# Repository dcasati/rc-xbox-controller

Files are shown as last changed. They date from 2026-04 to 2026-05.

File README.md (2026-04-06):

# RC Xbox Controller

Control your RC car using an Xbox Controller over Bluetooth Low Energy (BLE) with an ESP32-WROOM microcontroller.

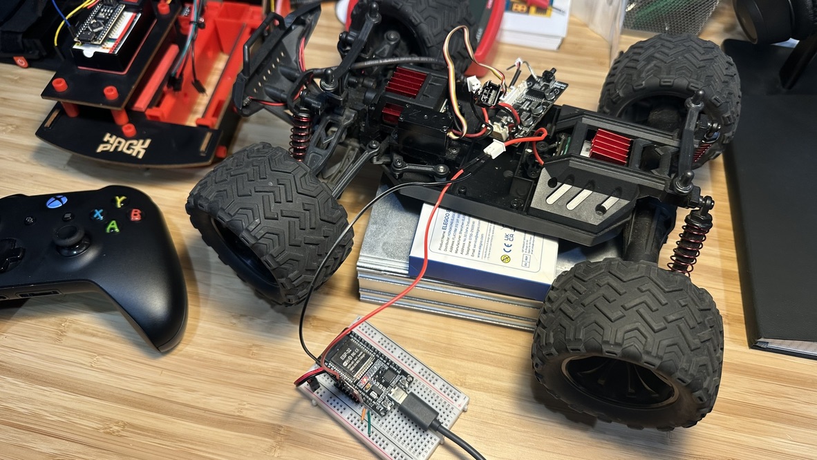
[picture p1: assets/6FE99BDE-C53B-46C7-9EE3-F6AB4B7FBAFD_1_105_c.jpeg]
RC Car


## Overview

This project replaces the standard RC car controller with an ESP32-WROOM that receives input from an Xbox Controller via BLE using [Bluepad32](https://github.com/ricardoquesada/bluepad32). The system controls:

- **Drive Motor**: Forward/backward movement using Xbox triggers (LT/RT)
- **Steering**: Left/right direction using left thumbstick X-axis
- **Headlights**: LED control toggled with the Y button

## Hardware

### Components
- **ESP32-WROOM** (4MB flash)
- **TB6612FNG H-Bridge** motor driver
- **DC Drive Motor** (rear wheels)
- **Stepper Motor** (front wheel steering)
- **LED** (headlights)
- **Xbox Controller** (Bluetooth)

### Wiring

| Component | GPIO | Function |
|---|---|---|
| Drive Motor PWM | 27 | PWMA |
| Drive Motor Direction | 25, 26 | AIN1, AIN2 |
| Steering PWM | 14 | PWMB |
| Steering Direction | 32, 33 | BIN1, BIN2 |
| Standby | 12 | STBY (HIGH) |
| Headlight LED | 4 | Output |

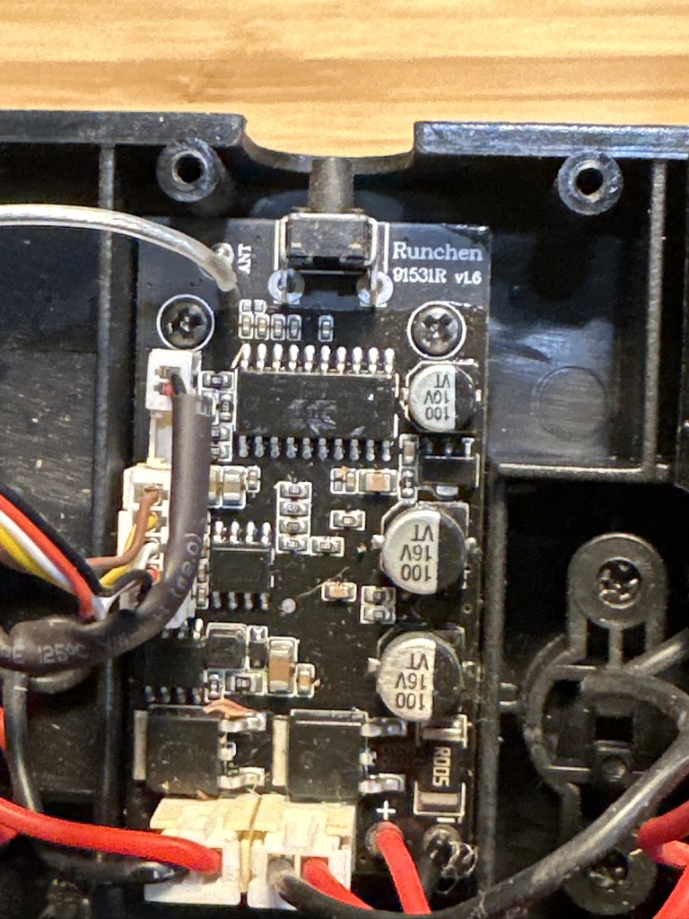
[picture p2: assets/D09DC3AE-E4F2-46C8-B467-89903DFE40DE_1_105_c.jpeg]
Hardware Setup


## Software Architecture

### Project Structure
```
rc-xbox-controller/
├── CMakeLists.txt          # ESP-IDF project config
├── sdkconfig.defaults      # Default build configuration
├── main/
│   ├── main.c              # Application entry point
│   ├── led.c/.h            # Headlight control
│   ├── motor_control.c/.h  # Drive motor (TB6612FNG Channel A)
│   ├── steering.c/.h       # Steering motor (TB6612FNG Channel B)
│   └── my_platform.c/.h    # Bluepad32 platform integration
├── hardware/               # KiCad PCB design files
├── Documents/              # Project documentation
└── assets/                 # Project images
```

### Control Mapping

| Xbox Input | Function | Range |
|---|---|---|
| Left Trigger (LT) | Forward speed | 0-1023 → PWM |
| Right Trigger (RT) | Reverse speed | 0-1023 → PWM |
| Left Stick X-axis | Steering | -512 to +511 |
| Y Button | Toggle headlights | On/Off |

## Build & Flash

### Prerequisites

1. **ESP-IDF v5.4.1** or later
   ```bash
   # Follow ESP-IDF installation guide
   # https://docs.espressif.com/projects/esp-idf/en/latest/esp32/get-started/
   ```

2. **Bluepad32** component
   ```bash
   # Clone Bluepad32 to your ESP components directory
   cd ~/esp
   git clone --recursive https://github.com/ricardoquesada/bluepad32.git
   ```

3. **BTstack** integration
   ```bash
   cd ~/esp/bluepad32/external/btstack
   python integrate_btstack.py
   ```

### Build

```bash
# Set up ESP-IDF environment
get_idf

# Navigate to project directory
cd /path/to/rc-xbox-controller

# Set target (first time only)
idf.py set-target esp32

# Build project
idf.py build

# Flash to ESP32
idf.py -p /dev/ttyUSB0 flash monitor
```

### Wi-Fi Configuration

Wi-Fi credentials are needed for OTA firmware updates. Since `sdkconfig` is gitignored, each developer must configure credentials locally.

**Option 1 — Interactive menu (recommended):**

```bash
get_idf
idf.py menuconfig
```

Navigate to **RC Xbox Controller Config** and set:
- **Wi-Fi SSID** — your network name
- **Wi-Fi Password** — your network password

Save and exit. Then rebuild with `idf.py build`.

**Option 2 — Command line (no menu):**

```bash
idf.py menuconfig --set "CONFIG_RC_WIFI_SSID=YourNetworkName" --set "CONFIG_RC_WIFI_PASSWORD=YourPassword"
idf.py build
```

**Option 3 — Edit `sdkconfig.defaults` (shared defaults):**

Add your credentials to `sdkconfig.defaults` if you want them as the default for new builds:

```
CONFIG_RC_WIFI_SSID="YourNetworkName"
CONFIG_RC_WIFI_PASSWORD="YourPassword"
```

Then do a clean build: `idf.py fullclean && idf.py build`

> **Note:** Do not commit real credentials. The defaults in `Kconfig.projbuild` are placeholder values (`myssid` / `mypassword`).

### OTA Firmware Update

Once connected to Wi-Fi, the ESP32 starts an HTTP server on port 80. To update firmware over-the-air:

1. Build the project: `idf.py build`
2. Find the ESP32's IP address in the serial monitor output (logged on boot)
3. Open `http://<ESP32_IP>/` in a browser
4. Select the `.bin` file from `build/rc_xbox_controller.bin`
5. Click **Upload & Flash** — the device reboots automatically

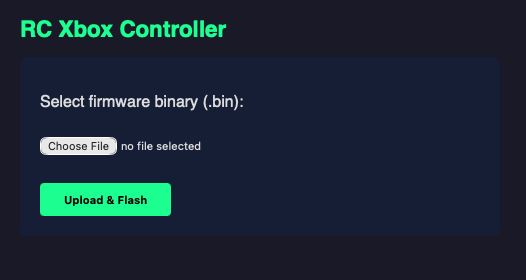
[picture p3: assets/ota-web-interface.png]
OTA Web Interface


## Usage

1. **Power on** the ESP32 and the RC car
2. **Pair** your Xbox Controller with the ESP32 (automatic BLE discovery)
3. **Drive**:
   - Press **LT** to move forward
   - Press **RT** to move backward
   - Move **left stick** left/right to steer
   - Press **Y** to toggle headlights
4. **Safety**: Motors automatically stop when the controller disconnects

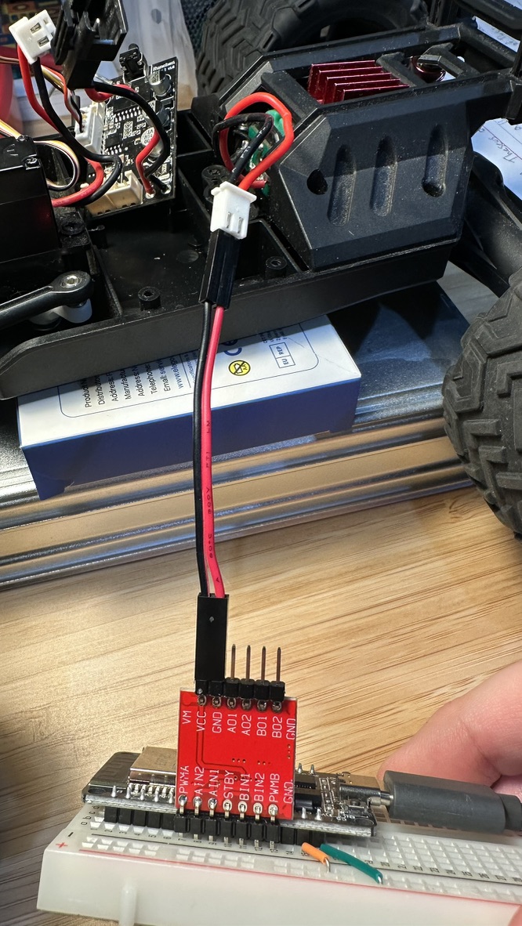
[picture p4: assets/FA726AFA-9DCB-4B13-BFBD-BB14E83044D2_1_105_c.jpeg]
Working Project


## Implementation Status

### ✅ Phase 1 — Complete
- [x] BLE Xbox Controller integration (Bluepad32)
- [x] Drive motor control (forward/backward via triggers)
- [x] Steering control (via thumbstick)
- [x] LED headlight toggle (Y button)
- [x] Disconnect safety (motors stop on BLE disconnect)

### ✅ Phase 2 — Complete
- [x] Wi-Fi station connectivity
- [x] OTA firmware updates via web interface
- [x] Structured logging with ESP_LOG per-module tags
- [ ] Tuning & polish (Task 2.5)

## Development Notes

- **Dead-zone threshold**: 5% trigger range prevents motor hum at rest
- **Stepper limits**: Max step count configured to prevent mechanical over-travel
- **PWM frequency**: Default LEDC configuration for smooth motor control
- **BLE callbacks**: High-priority FreeRTOS task processes Bluepad32 events

## References

- [ESP-IDF Documentation](https://docs.espressif.com/projects/esp-idf/en/latest/esp32/)
- [Bluepad32 GitHub](https://github.com/ricardoquesada/bluepad32)
- [TB6612FNG Datasheet](https://www.sparkfun.com/datasheets/Robotics/TB6612FNG.pdf)
- [Project Documentation](Documents/)

## Gallery

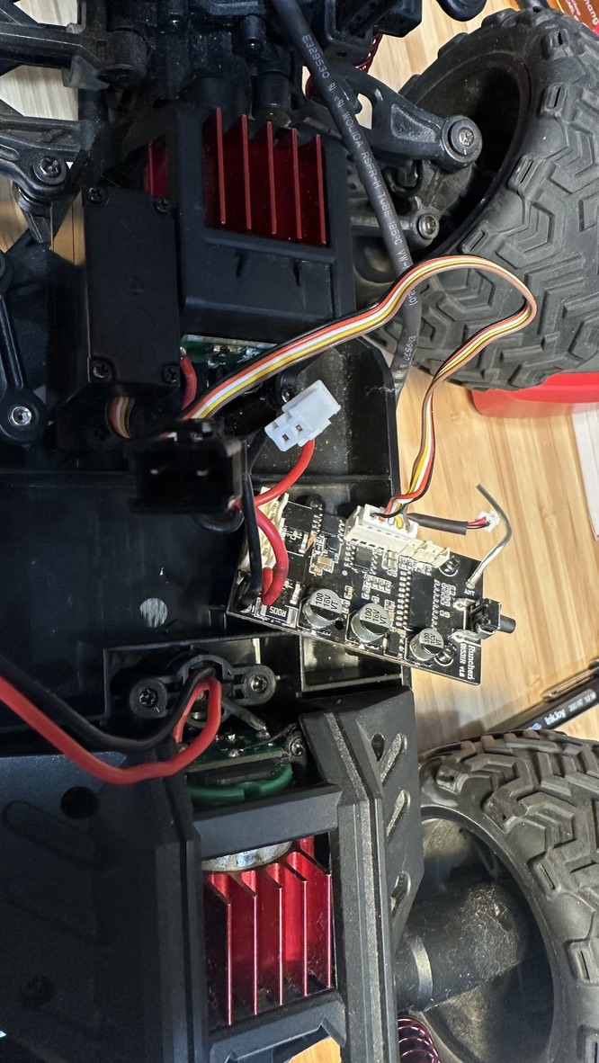
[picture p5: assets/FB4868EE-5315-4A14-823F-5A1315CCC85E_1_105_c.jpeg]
Car Interior


## License

MIT License - See LICENSE file for details

## Contributing

Pull requests welcome! Please follow ESP-IDF coding standards and test thoroughly before submitting.

## Author

Built with ESP-IDF, Bluepad32, and ❤️ for RC cars

---

**Repository**: https://github.com/dcasati/rc-xbox-controller

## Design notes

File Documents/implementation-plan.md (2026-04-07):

# Implementation Plan
## RC Xbox Controller — ESP32-WROOM

Based on [FSD.md](FSD.md) v1.0

---

## Project Structure

```
rc-xbox-controller/
├── CMakeLists.txt
├── sdkconfig.defaults
├── partitions.csv                  # OTA partition table
├── main/
│   ├── CMakeLists.txt
│   ├── main.c                      # App entry, task init
│   ├── Kconfig.projbuild           # Wi-Fi SSID/password menu
│   ├── ble_controller.c/.h         # Bluepad32 BLE host
│   ├── motor_control.c/.h          # TB6612FNG Channel A (drive)
│   ├── steering.c/.h               # TB6612FNG Channel B (stepper)
│   ├── led.c/.h                    # Headlight GPIO
│   ├── ota.c/.h                    # OTA update handler
│   ├── wifi.c/.h                   # Wi-Fi STA connection
│   └── webserver.c/.h              # HTTP server for OTA upload
├── components/
│   └── bluepad32/                  # Bluepad32 (git submodule)
└── Documents/
    ├── FSD.md
    └── rc-xbox-controller-project-idea.md
```

---

## Phase 1 — Motor Control & BLE Driving

### Task 1.1: Project Scaffolding
- [x] Create ESP-IDF project structure (`CMakeLists.txt`, `main/`)
- [x] Add Bluepad32 as a component (git submodule under `components/`)
- [x] Configure `sdkconfig.defaults` for ESP32-WROOM (BLE enabled, flash 4MB)
- [x] Set target to `esp32`, verify blank project builds
- **Depends on:** nothing

### Task 1.2: BLE Controller Integration
- [x] Implement `ble_controller.c/.h` — init Bluepad32, register callbacks
- [x] Handle `onConnectedGamepad` / `onDisconnectedGamepad` events
- [x] Parse Xbox Controller inputs: LT, RT, left thumbstick X-axis, Y button
- [x] Log raw input values over serial for validation
- **Depends on:** 1.1
- **Validates:** BLE-01, BLE-02, BLE-03

### Task 1.3: Drive Motor Control (TB6612FNG Channel A)
- [x] Implement `motor_control.c/.h`
- [x] Configure LEDC PWM on GPIO 27 (PWMA), GPIOs 25/26 (AIN1/AIN2)
- [x] Configure GPIO 12 (STBY) — pull HIGH on init
- [x] `motor_set_speed(int16_t speed)` — positive = forward, negative = reverse, 0 = brake
- [x] Map LT (0–1023) → forward PWM, RT (0–1023) → reverse PWM
- [x] Add dead-zone threshold (~5% of trigger range) to avoid motor hum at rest
- **Depends on:** 1.1
- **Validates:** MOT-01 through MOT-05

### Task 1.4: Steering Control (TB6612FNG Channel B)
- [x] Implement `steering.c/.h`
- [x] Configure LEDC PWM on GPIO 14 (PWMB), GPIOs 32/33 (BIN1/BIN2)
- [x] `steering_set_position(int16_t x_axis)` — map thumbstick X to stepper direction/speed
- [x] Add configurable max step count constant to prevent mechanical over-travel
- [x] Center position (thumbstick = 0) → stop stepper
- **Depends on:** 1.1
- **Validates:** STR-01 through STR-05

### Task 1.5: End-to-End Integration
- [x] Wire BLE callbacks → motor + steering functions in `main.c`
- [x] Create `ble_task` (FreeRTOS, priority high) — poll Bluepad32
- [x] Create `motor_task` (FreeRTOS, priority high) — consume input queue, apply PWM
- [x] Add BLE disconnect safety: stop motors + stepper on disconnect
- [x] Flash to ESP32, test with Xbox Controller + motors on bench
- **Depends on:** 1.2, 1.3, 1.4
- **Validates:** BLE-04, full Phase 1

### Phase 1 Milestone
> Xbox Controller connected over BLE drives front+rear DC motors via triggers and steers via thumbstick. Disconnect stops all outputs.

---

## Phase 2 — Headlights & Enhancements

### Task 2.1: Headlight LED Control
- [x] Implement `led.c/.h`
- [x] Configure GPIO 13 as output
- [x] `led_toggle()`, `led_set(bool on)`, `led_off()`
- [x] Wire Y button press (with debounce) → `led_toggle()`
- [x] Call `led_off()` on BLE disconnect
- **Depends on:** Phase 1
- **Validates:** LED-01, LED-02, LED-03

### Task 2.2: Wi-Fi Station Connection
- [x] Implement `wifi.c/.h`
- [x] Add `Kconfig.projbuild` for SSID/password configuration
- [x] Connect to Wi-Fi on boot using ESP-IDF `esp_wifi` API
- [x] Log IP address on successful connection
- **Depends on:** Phase 1
- **Validates:** OTA-03

### Task 2.3: OTA Web Interface
- [x] Implement `webserver.c/.h` — start `httpd_server` on port 80
- [x] Serve HTML upload form at `GET /`
- [x] Handle firmware binary upload at `POST /ota`
- [x] Implement `ota.c/.h` — write to OTA partition, validate, reboot
- [x] Create OTA partition table (`partitions.csv`: factory + ota_0 + ota_1)
- **Depends on:** 2.2
- **Validates:** OTA-01, OTA-02

### Task 2.4: Logging
- [x] Implement structured serial logging for all subsystems
- [x] Log: BLE state, trigger values, PWM duty, thumbstick X, LED state
- [x] Use ESP-IDF `ESP_LOG` macros with per-module tags
- **Depends on:** Phase 1
- **Validates:** OTA-04, OTA-05

### Task 2.5: Tuning & Polish
- [ ] Tune dead-zone for trigger center (~5%) and thumbstick center (~10%)
- [ ] Tune max steering angle / step count
- [ ] Verify latency < 50 ms (BLE input → motor output)
- [ ] Stress test: 1+ hour continuous operation
- **Depends on:** 2.1, 2.3, 2.4
- **Validates:** NFR-01, NFR-02, NFR-03

### Phase 2 Milestone
> Full system operational: BLE driving, headlights, Wi-Fi OTA, serial logging. Ready for in-car testing.

---

## GPIO Summary

| GPIO | Function | Direction |
|---|---|---|
| 4 | Front LED | Output |
| 12 | PWMB (steering PWM) | PWM Output |
| 14 | BIN2 (steer dir B) | Output |
| 25 | AIN1 (drive dir A) | Output |
| 26 | TB6612FNG STBY | Output |
| 27 | BIN1 (steer dir A) | Output |
| 32 | PWMA (drive PWM) | PWM Output |
| 33 | AIN2 (drive dir B) | Output |

---

## Dependencies

| Dependency | Version | Source |
|---|---|---|
| ESP-IDF | v5.4.1 | `~/esp/esp-idf` (installed) |
| [Bluepad32](https://github.com/ricardoquesada/bluepad32) | latest | `components/bluepad32` (git submodule) |

---

## Build & Flash

```bash
get_idf                              # activate ESP-IDF environment
cd /Volumes/Extreme\ SSD/src/rc-xbox-controller
idf.py set-target esp32
idf.py build
idf.py -p /dev/cu.usbserial-* flash monitor
```

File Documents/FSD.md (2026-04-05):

# Functional Specification Document
## RC Xbox Controller — ESP32-WROOM

**Version:** 1.0  
**Date:** April 4, 2026  
**Repository:** https://github.com/dcasati/rc-xbox-controller

---

## 1. Overview

This project replaces the standard RC car controller with an Xbox Controller connected over BLE to an ESP32-WROOM. The ESP32 acts as the BLE host (via [Bluepad32](https://github.com/ricardoquesada/bluepad32)), interprets controller inputs, and drives the car's motors and headlights through a TB6612FNG H-Bridge motor driver.

---

## 2. System Architecture

```
[Xbox Controller]
      |
      | BLE (Bluepad32)
      |
[ESP32-WROOM]
      |
      |--- UART/USB -------> Serial Logging
      |--- Wi-Fi ----------> OTA Web Interface
      |
[TB6612FNG H-Bridge] (VM = 5V)
      |
      |--- Channel A (PWM/DIR) ---> Front + Rear DC Motors (propulsion, wired in parallel)
      |
      |--- Channel B (PWM/DIR) ---> Steering Motor (DC + potentiometer feedback)
      |
      |--- GPIO -------> Front LED (headlights)
```

---

## 3. Hardware Components

| Component | Description |
|---|---|
| ESP32-WROOM | Main microcontroller; BLE host, motor control |
| Xbox Controller | User input device; connects over BLE |
| TB6612FNG H-Bridge | Dual-channel motor driver; VM = 5V |
| Front DC Motor | Propulsion — forward / backward (wired in parallel with rear) |
| Rear DC Motor | Propulsion — forward / backward (wired in parallel with front) |
| Front Steering Servo | Steering — DC motor + potentiometer feedback, driven via TB6612FNG Channel B |
| Front LED | Headlights — on / off |
| USB Cable | Power + serial logging |

---

## 4. Functional Requirements

### 4.1 BLE & Controller Connectivity

| ID | Requirement |
|---|---|
| BLE-01 | The ESP32 shall initialize as a BLE host using the [Bluepad32](https://github.com/ricardoquesada/bluepad32) library. |
| BLE-02 | The ESP32 shall accept a pairing request from an Xbox Controller. |
| BLE-03 | The system shall reconnect automatically to the last paired controller on power-up. |
| BLE-04 | Controller disconnection shall immediately stop all motor outputs and turn off headlights. |

### 4.2 Propulsion (Front + Rear DC Motors)

The front and rear DC motors are wired in parallel on TB6612FNG Channel A. They always run at the same speed and direction. Motor supply voltage is 5V.

| ID | Requirement |
|---|---|
| MOT-01 | The left trigger (LT) shall control forward drive speed; the right trigger (RT) shall control reverse drive speed. |
| MOT-02 | Pressing LT shall drive the motors in the forward direction. |
| MOT-03 | Pressing RT shall drive the motors in reverse. |
| MOT-04 | Motor speed shall be proportional to trigger deflection (0–100% PWM). |
| MOT-05 | Releasing both triggers shall brake the motors (STBY or coast configurable). |

### 4.3 Steering (Front Servo)

| ID | Requirement |
|---|---|
| STR-01 | The left thumbstick X-axis shall control the front steering servo. |
| STR-02 | Deflecting left shall move the servo to the left steering position. |
| STR-03 | Deflecting right shall move the servo to the right steering position. |
| STR-04 | Returning the thumbstick to center shall return the servo to the center position. |
| STR-05 | Servo pulse range (1.0–2.0ms at 50Hz) shall be configurable to prevent mechanical over-travel. |

### 4.4 Headlights (Front LED)

| ID | Requirement |
|---|---|
| LED-01 | Pressing the **Y button** on the Xbox Controller shall toggle the front LED on and off. |
| LED-02 | The LED state shall persist across steering and speed changes. |
| LED-03 | On BLE disconnect, the LED shall turn off. |

### 4.5 OTA & Logging

| ID | Requirement |
|---|---|
| OTA-01 | The firmware shall support OTA updates over Wi-Fi using the ESP-IDF OTA partition scheme. |
| OTA-02 | A basic web interface (HTTP server on the ESP32) shall allow the user to upload a new firmware binary. |
| OTA-03 | The ESP32 shall connect to a configured Wi-Fi network on boot (SSID/password stored in NVS or sdkconfig). |
| OTA-04 | Serial logging shall be available over USB at 115200 baud. |
| OTA-05 | Log output shall include BLE connection state, controller input values, motor PWM duty cycles, and LED state. |

---

## 5. Xbox Controller Button Mapping

| Xbox Input | Function |
|---|---|
| Left Trigger (LT) | Drive forward (proportional) |
| Right Trigger (RT) | Drive backward (proportional) |
| Left Thumbstick X+ | Steer right |
| Left Thumbstick X− | Steer left |
| Y Button | Toggle headlights |

> Additional mappings (e.g., bumpers for turbo, Menu for OTA trigger) to be defined in Phase 2.

---

## 6. Pin Mapping (Verified)

| Signal | ESP32 Pin | ESP32-WROOM-32 Module Pin | TB6612FNG Pin | Function |
|---|---|---|---|---|
| AIN1 | GPIO 25 | IO25 (pin 10) | pin 14 | Drive motors direction A |
| AIN2 | GPIO 33 | IO33 (pin 9) | pin 15 | Drive motors direction B |
| PWMA | GPIO 32 | IO32 (pin 8) | pin 16 | Drive motors PWM |
| STBY | GPIO 26 | IO26 (pin 11) | — | H-Bridge standby (HIGH = enabled) |
| BIN1 | GPIO 27 | IO27 (pin 12) | pin 12 | Steering motor direction A |
| BIN2 | GPIO 14 | IO14 (pin 13) | pin 11 | Steering motor direction B |
| PWMB | GPIO 12 | IO12 (pin 14) | pin 10 | Steering motor PWM |
| POT | GPIO 34 | IO34 (pin 6) | — | Steering potentiometer wiper (ADC input) |
| LED | GPIO 13 | IO13 (pin 16) | — | Front LED headlight |
| VDD | 3.3V | VDD (pin 2) | VCC (pin 2) | Logic power |
| GND | GND | GND (pin 1) | GND (pins 3,8,9) | Common ground |
| VM | — | — | VM (pin 1) | Motor power: 5V (regulated from battery) |

### TB6612FNG Motor Outputs

| TB6612FNG Pin | Connected to | Notes |
|---|---|---|
| AO1 (pin 4) | Drive motor wire 1 | Front + rear DC motors wired in parallel |
| AO2 (pin 5) | Drive motor wire 2 | Swap AO1/AO2 if direction is reversed |
| BO1 (pin 7) | Steering servo RED wire | Motor + |
| BO2 (pin 6) | Steering servo BLACK wire | Motor − |

### 5-Wire Steering Servo

| Wire Color | Connect to | Function |
|---|---|---|
| Red | TB6612FNG BO1 (pin 7) | Motor + |
| Black | TB6612FNG BO2 (pin 6) | Motor − |
| White | ESP32 3.3V | Potentiometer VCC |
| Yellow | ESP32 GPIO 34 | Potentiometer wiper (ADC) |
| Brown | ESP32 GND | Potentiometer GND |

### Additional Components

| Component | Connection | Notes |
|---|---|---|
| 100nF ceramic cap | GPIO 34 ↔ GND | Required: filters motor EMI on ADC |
| 220Ω resistor | GPIO 13 → LED → GND | Current limiting for headlight LED |
| 7.4V Li-ion battery | VM + GND on TB6612FNG | 2S 18650, 1500mAh (regulated to 5V for VM) |

---

## 7. Software Architecture

### 7.1 Firmware Components

| Component | Responsibility |
|---|---|
| `main.c` | App entry point; task initialization |
| `ble_controller.c/.h` | Bluepad32 integration; BLE event handling |
| `motor_control.c/.h` | TB6612FNG PWM/direction control for both motors |
| `steering.c/.h` | DC motor + potentiometer closed-loop position control |
| `led.c/.h` | Headlight GPIO control |
| `ota.c/.h` | OTA update handler |
| `wifi.c/.h` | Wi-Fi station connection |
| `webserver.c/.h` | HTTP server for OTA upload page |

### 7.2 FreeRTOS Tasks

| Task | Priority | Description |
|---|---|---|
| `ble_task` | High | Polls Bluepad2 for controller events |
| `motor_task` | High | Applies PWM updates from BLE input queue |
| `ota_task` | Low | HTTP server for OTA firmware upload |
| `log_task` | Low | Periodic status logging over UART |

### 7.3 Framework & Libraries

| Tool / Library | Purpose |
|---|---|
| ESP-IDF v5.4.x | Base SDK, FreeRTOS, Wi-Fi, OTA, BLE |
| [Bluepad32](https://github.com/ricardoquesada/bluepad32) | Xbox Controller BLE host library |
| ESP32-Workbench | Flashing, testing, serial monitoring |

---

## 8. Implementation Phases

### Phase 1 — Motor Control & BLE Driving
- [ ] Initialize Bluepad2 and pair with Xbox Controller
- [ ] Implement rear DC motor forward/backward via TB6612FNG
- [ ] Implement front stepper motor left/right steering
- [ ] Map thumbstick axes to motor PWM
- [ ] Validate over BLE end-to-end

### Phase 2 — Headlights & Enhancements
- [ ] Implement LED toggle on Y button press
- [ ] Add BLE disconnect safety stop
- [ ] Add OTA update support
- [ ] Serial logging for all subsystems
- [ ] Tuning: dead-zone on thumbstick center, max steering angle

---

## 9. Non-Functional Requirements

| ID | Requirement |
|---|---|
| NFR-01 | BLE input-to-motor latency shall be < 50 ms. |
| NFR-02 | Firmware shall fit within 2 MB flash (single OTA partition scheme). |
| NFR-03 | System shall be stable for continuous operation > 1 hour without reboot. |
| NFR-04 | All source code shall be hosted at https://github.com/dcasati/rc-xbox-controller. |

---

## 10. Resolved Questions

| # | Question | Answer |
|---|---|---|
| 1 | Is the front motor a true stepper (step/dir) or a DC motor used for steering? | It is a servo. Direct PWM from ESP32 GPIO (no H-Bridge needed). Two DC motors (front + rear) for propulsion. |
| 2 | What is the supply voltage for the motors? | Measured 4.6–5V (within TB6612FNG range). |
| 3 | Should OTA be triggered automatically or via a dedicated button press? | Basic web interface served by the ESP32 over Wi-Fi. |
| 4 | Is Wi-Fi available in the RC car environment? | Yes. Wi-Fi OTA will be used. |

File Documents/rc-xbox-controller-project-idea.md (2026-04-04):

# rc xbox controller project

The rc xbox controller a solution consisting of an ESP32 wroom that replaces the standard controller from a RC car. The XBOX Controller communicates with the ESP32 over BLE using [Bluepad32](https://github.com/ricardoquesada/bluepad32). Together allow for someone to operate the car using a XBOX controller.

## Main Function

I want to use an XBOX Controller to control my RC car over BLE on ESP32-WROOM.

The ESP32 should control the car two motors. There is a step motor that controls the left and right direction of the front wheels. There is another motor on the back that controls the speed of the RC car. There is also a LED in front of the car that functions as headlights.

To control the motors, we will use a TB6612FNG H-Bridge 

Because we use a USB for the project, the ESP32 should use OTA flashing and logging. 

## Implementation Phases

1. Implement all of the basic ESP32 functions, including driving forward, backward and turning left and right using the xbox controller over BLE.
2. Implement a function that allows for the LEDs to be turned on and off using the xbox controller over BLE.

## Tools

Use ESP-IDF and Apple native tools for the project.
Use the ESP32-workbench (https://github.com/SensorsIot/Universal-ESP32-Workbench) with its skills for flashing, testing.

Create a new GitHub Repository on https://github.com/dcasati/rc-xbox-controller

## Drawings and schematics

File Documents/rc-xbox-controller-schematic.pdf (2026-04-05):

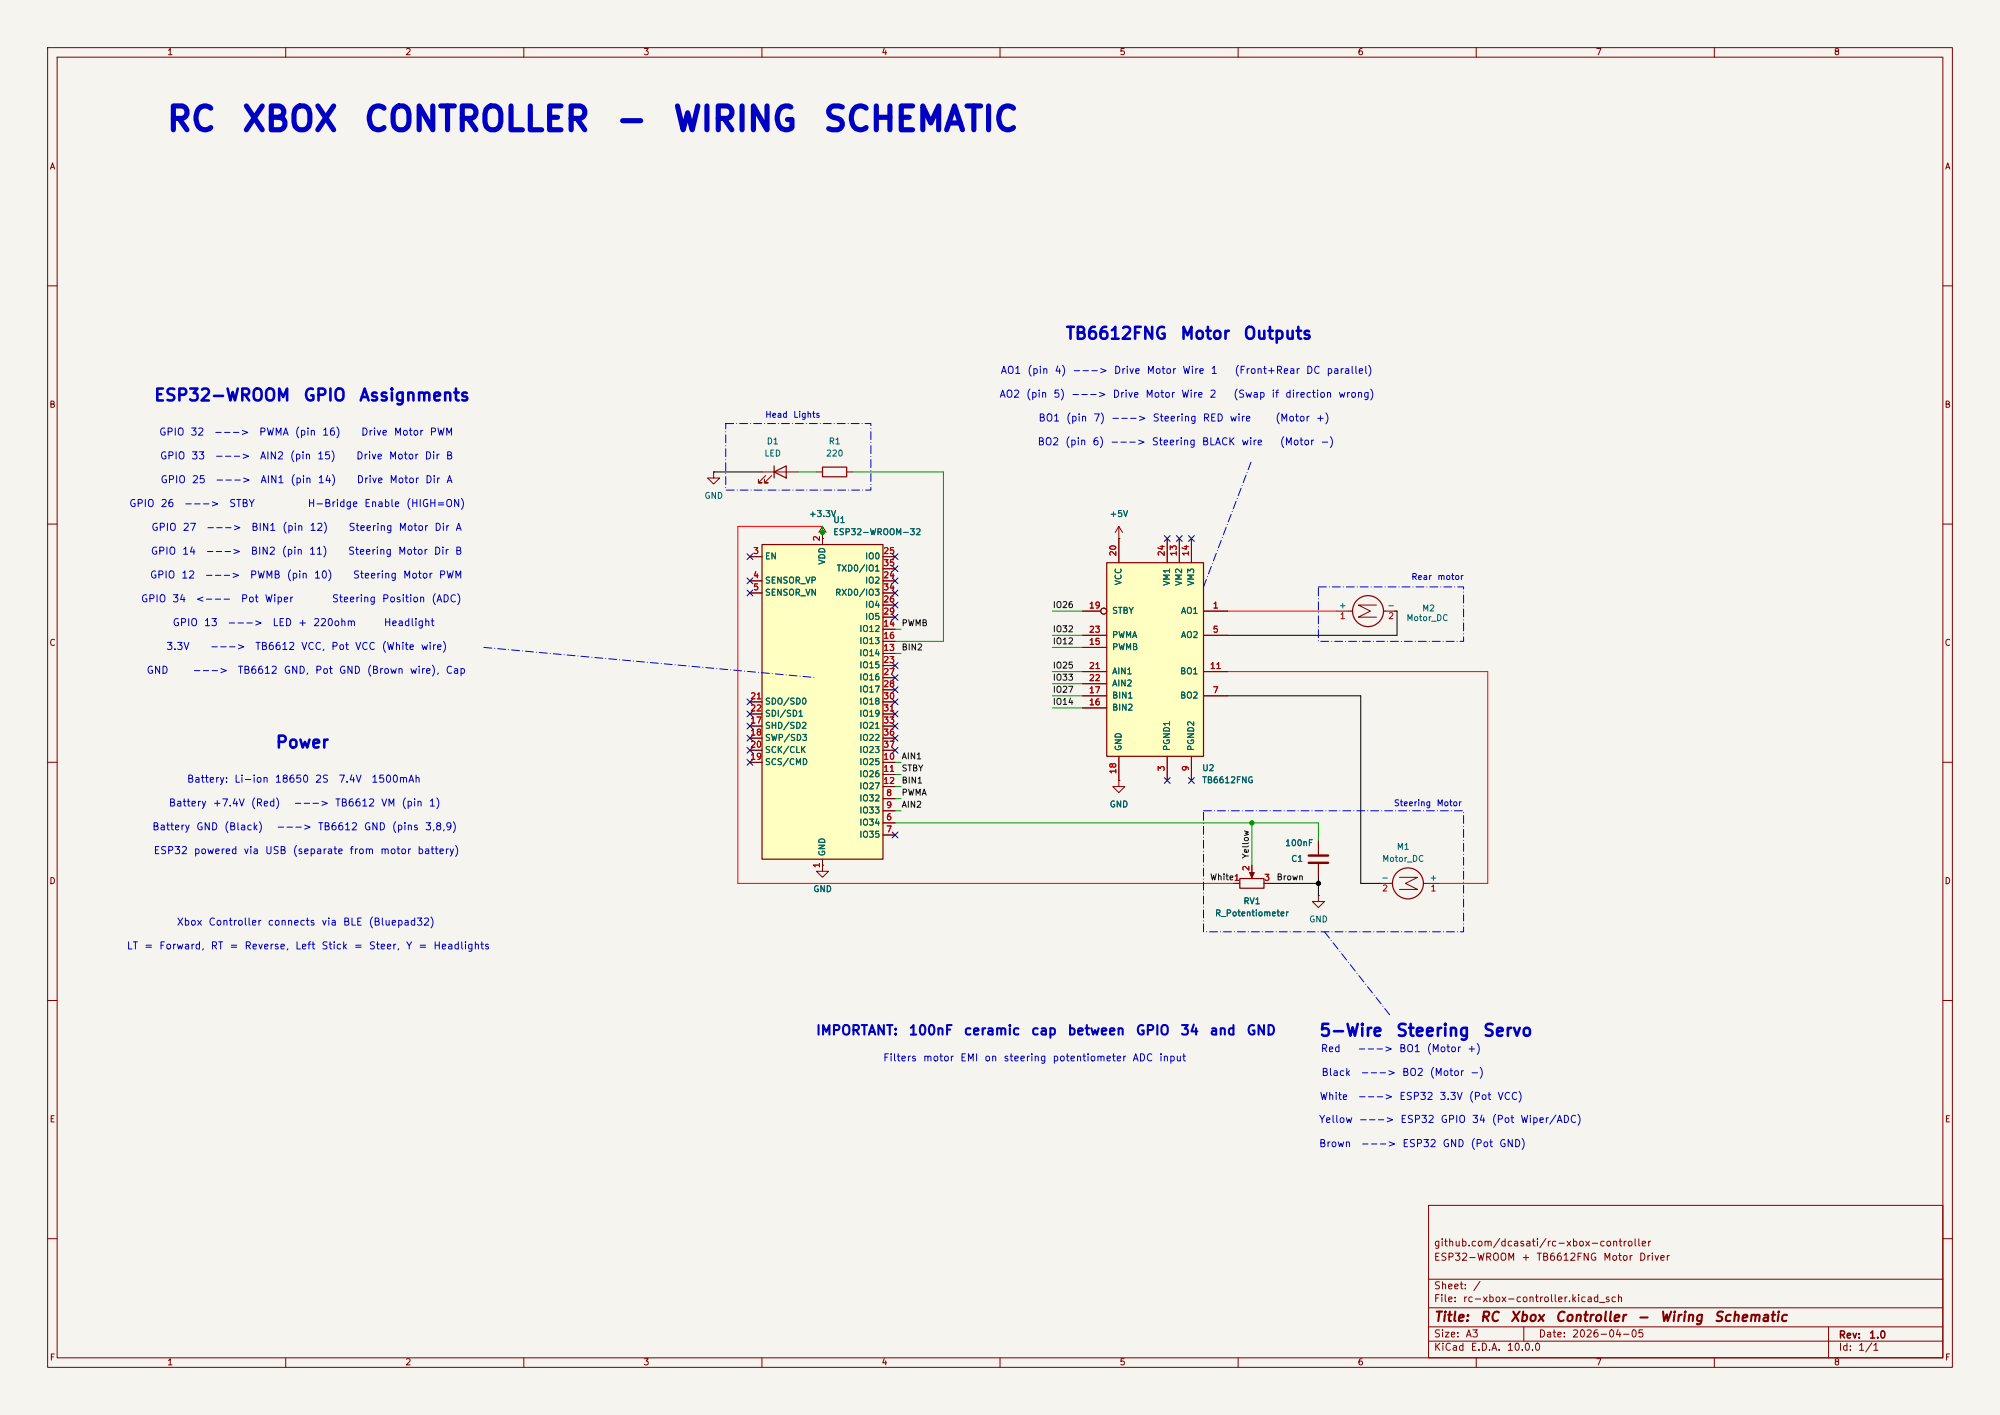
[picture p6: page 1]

IO26 RC XBOX CONTROLLER - WIRING SCHEMATIC

ESP32 powered via USB (separate from motor battery)

Xbox Controller connects via BLE (Bluepad32)

LT = Forward, RT = Reverse, Left Stick = Steer, Y = Headlights

IMPORTANT: 100nF ceramic cap between GPIO 34 and GND

Filters motor EMI on steering potentiometer ADC input

Yellow ---> ESP32 GPIO 34 (Pot Wiper/ADC)

Brown ---> ESP32 GND (Pot GND)

ESP32-WROOM + TB6612FNG Motor Driver github.com/dcasati/rc-xbox-controller

Sheet: /
File: rc-xbox-controller.kicad_sch
Title: RC Xbox Controller - Wiring Schematic

Size: A3 | Rev: 1.0 | F Date: 2026-04-05 KiCad E.D.A. 10.0.0

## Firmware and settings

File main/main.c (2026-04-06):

// SPDX-License-Identifier: MIT
// RC Xbox Controller — Main Entry Point

#include <stdlib.h>

#include <btstack_port_esp32.h>
#include <btstack_run_loop.h>
#include <btstack_stdio_esp32.h>
#include <esp_log.h>
#include <nvs_flash.h>
#include <uni.h>

#include "sdkconfig.h"
#include "webserver.h"
#include "wifi.h"

static const char* TAG = "main";

#ifndef CONFIG_BLUEPAD32_PLATFORM_CUSTOM
#error "Must use BLUEPAD32_PLATFORM_CUSTOM"
#endif

// Defined in my_platform.c
struct uni_platform* get_my_platform(void);

int app_main(void) {
#ifdef CONFIG_ESP_CONSOLE_UART
#ifndef CONFIG_BLUEPAD32_USB_CONSOLE_ENABLE
    btstack_stdio_init();
#endif
#endif

    // Initialize NVS — required by Wi-Fi
    esp_err_t ret = nvs_flash_init();
    if (ret == ESP_ERR_NVS_NO_FREE_PAGES || ret == ESP_ERR_NVS_NEW_VERSION_FOUND) {
        ESP_ERROR_CHECK(nvs_flash_erase());
        ret = nvs_flash_init();
    }
    ESP_ERROR_CHECK(ret);

    // Connect to Wi-Fi and start OTA web server
    ESP_LOGI(TAG, "Starting Wi-Fi...");
    if (wifi_init_sta() == ESP_OK) {
        ESP_LOGI(TAG, "Starting OTA web server...");
        webserver_start();
    } else {
        ESP_LOGW(TAG, "Wi-Fi failed — OTA disabled, BLE-only mode");
    }

    // Configure BTstack for ESP32 VHCI Controller
    btstack_init();

    // Set our custom platform before init
    uni_platform_set_custom(get_my_platform());

    // Init Bluepad32 — does not return from btstack_run_loop_execute()
    uni_init(0, NULL);
    btstack_run_loop_execute();

    return 0;
}

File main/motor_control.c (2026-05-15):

// SPDX-License-Identifier: MIT
// RC Xbox Controller — Motor Control (BTS7960 43A H-Bridge)

#include "motor_control.h"

#include <driver/gpio.h>
#include <driver/ledc.h>
#include <esp_log.h>

static const char* TAG = "motor";

// BTS7960 H-Bridge — Drive motors (front + rear in parallel)
// RPWM: forward PWM input  (HIGH = forward, duty sets speed)
// LPWM: reverse PWM input  (HIGH = reverse, duty sets speed)
// R_EN: right/forward half-bridge enable (active HIGH)
// L_EN: left/reverse  half-bridge enable (active HIGH)
#define MOTOR_RPWM_GPIO  GPIO_NUM_32
#define MOTOR_LPWM_GPIO  GPIO_NUM_33
#define MOTOR_R_EN_GPIO  GPIO_NUM_25
#define MOTOR_L_EN_GPIO  GPIO_NUM_26

// LEDC config — two channels share one timer
// NOTE: LEDC_CHANNEL_0 and LEDC_CHANNEL_1 are used here;
//       steering.c uses LEDC_CHANNEL_2 / LEDC_TIMER_1 to avoid conflict.
#define MOTOR_RPWM_CHANNEL   LEDC_CHANNEL_0
#define MOTOR_LPWM_CHANNEL   LEDC_CHANNEL_1
#define MOTOR_PWM_TIMER      LEDC_TIMER_0
#define MOTOR_PWM_FREQ_HZ    20000              // 20 kHz — within BTS7960's 25 kHz limit
#define MOTOR_PWM_RESOLUTION LEDC_TIMER_10_BIT // 0–1023, matches gamepad trigger range

// Dead zone: ignore trigger values below this threshold (~5% of 1023)
#define MOTOR_DEAD_ZONE  50

static int32_t last_logged_speed = 0;

void motor_control_init(void) {
    // Configure enable GPIOs
    gpio_config_t io_conf = {
        .pin_bit_mask = (1ULL << MOTOR_R_EN_GPIO) | (1ULL << MOTOR_L_EN_GPIO),
        .mode = GPIO_MODE_OUTPUT,
        .pull_up_en = GPIO_PULLUP_DISABLE,
        .pull_down_en = GPIO_PULLDOWN_DISABLE,
        .intr_type = GPIO_INTR_DISABLE,
    };
    gpio_config(&io_conf);

    // Enable both half-bridges
    gpio_set_level(MOTOR_R_EN_GPIO, 1);
    gpio_set_level(MOTOR_L_EN_GPIO, 1);

    // Configure LEDC timer shared by both PWM channels
    ledc_timer_config_t timer_conf = {
        .speed_mode = LEDC_HIGH_SPEED_MODE,
        .timer_num = MOTOR_PWM_TIMER,
        .duty_resolution = MOTOR_PWM_RESOLUTION,
        .freq_hz = MOTOR_PWM_FREQ_HZ,
        .clk_cfg = LEDC_AUTO_CLK,
    };
    ledc_timer_config(&timer_conf);

    // RPWM channel (forward direction)
    ledc_channel_config_t rpwm_conf = {
        .gpio_num = MOTOR_RPWM_GPIO,
        .speed_mode = LEDC_HIGH_SPEED_MODE,
        .channel = MOTOR_RPWM_CHANNEL,
        .timer_sel = MOTOR_PWM_TIMER,
        .duty = 0,
        .hpoint = 0,
    };
    ledc_channel_config(&rpwm_conf);

    // LPWM channel (reverse direction)
    ledc_channel_config_t lpwm_conf = {
        .gpio_num = MOTOR_LPWM_GPIO,
        .speed_mode = LEDC_HIGH_SPEED_MODE,
        .channel = MOTOR_LPWM_CHANNEL,
        .timer_sel = MOTOR_PWM_TIMER,
        .duty = 0,
        .hpoint = 0,
    };
    ledc_channel_config(&lpwm_conf);

    ESP_LOGI(TAG, "Drive motor initialized (BTS7960: RPWM=%d, LPWM=%d, R_EN=%d, L_EN=%d)",
             MOTOR_RPWM_GPIO, MOTOR_LPWM_GPIO, MOTOR_R_EN_GPIO, MOTOR_L_EN_GPIO);
}

void motor_set_speed(int32_t speed) {
    // Apply dead zone
    if (speed > -MOTOR_DEAD_ZONE && speed < MOTOR_DEAD_ZONE) {
        motor_stop();
        return;
    }

    uint32_t duty = (speed > 0) ? (uint32_t)speed : (uint32_t)(-speed);
    if (duty > 1023) duty = 1023;

    if (speed > 0) {
        // Forward: RPWM = duty, LPWM = 0
        ledc_set_duty(LEDC_HIGH_SPEED_MODE, MOTOR_LPWM_CHANNEL, 0);
        ledc_update_duty(LEDC_HIGH_SPEED_MODE, MOTOR_LPWM_CHANNEL);
        ledc_set_duty(LEDC_HIGH_SPEED_MODE, MOTOR_RPWM_CHANNEL, duty);
        ledc_update_duty(LEDC_HIGH_SPEED_MODE, MOTOR_RPWM_CHANNEL);
    } else {
        // Reverse: LPWM = duty, RPWM = 0
        ledc_set_duty(LEDC_HIGH_SPEED_MODE, MOTOR_RPWM_CHANNEL, 0);
        ledc_update_duty(LEDC_HIGH_SPEED_MODE, MOTOR_RPWM_CHANNEL);
        ledc_set_duty(LEDC_HIGH_SPEED_MODE, MOTOR_LPWM_CHANNEL, duty);
        ledc_update_duty(LEDC_HIGH_SPEED_MODE, MOTOR_LPWM_CHANNEL);
    }

    if (speed != last_logged_speed) {
        ESP_LOGI(TAG, "speed=%ld duty=%lu dir=%s", (long)speed, (unsigned long)duty,
                 speed > 0 ? "FWD" : "REV");
        last_logged_speed = speed;
    }
}

void motor_stop(void) {
    // Coast: both PWM inputs to 0 (motor coasts to a stop)
    ledc_set_duty(LEDC_HIGH_SPEED_MODE, MOTOR_RPWM_CHANNEL, 0);
    ledc_update_duty(LEDC_HIGH_SPEED_MODE, MOTOR_RPWM_CHANNEL);
    ledc_set_duty(LEDC_HIGH_SPEED_MODE, MOTOR_LPWM_CHANNEL, 0);
    ledc_update_duty(LEDC_HIGH_SPEED_MODE, MOTOR_LPWM_CHANNEL);
    last_logged_speed = 0;
}

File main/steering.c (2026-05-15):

// SPDX-License-Identifier: MIT
// RC Xbox Controller — Steering Control (TB6612FNG Channel B + potentiometer feedback)
//
// Drives a DC steering motor via TB6612FNG Channel B with closed-loop position
// control using a potentiometer wiper (ADC1_CH6 / GPIO 34).
//
// TB6612FNG Channel B wiring:
//   BIN1 → GPIO 27   (direction A)
//   BIN2 → GPIO 14   (direction B)
//   PWMB → GPIO 12   (PWM speed, LEDC CH2 / TIM1)
//   STBY → GPIO 26   (shared with drive motor; held HIGH by motor_control_init)
//   BO1  → Motor +
//   BO2  → Motor −
//
// Potentiometer wiring:
//   White  → ESP32 3.3 V
//   Yellow → GPIO 34   (ADC1_CH6, wiper)
//   Brown  → GND
//
// Pot is inverted: higher ADC value = left, lower = right.
// Calibrated values from hardware: CENTER=2160, LEFT=2475, RIGHT=1200.
// Left thumbstick X-axis (-512 … +511) maps to a target ADC count.
// A proportional controller drives the motor toward that target and coasts
// when the stick is in the dead zone or error is within tolerance.

#include "steering.h"

#include <stdlib.h>
#include <driver/gpio.h>
#include <driver/ledc.h>
#include <esp_adc/adc_oneshot.h>
#include <esp_log.h>

static const char *TAG = "steering";

// ---- TB6612FNG Channel B GPIOs ---------------------------------------------
#define STEER_BIN1_GPIO   GPIO_NUM_27
#define STEER_BIN2_GPIO   GPIO_NUM_14
#define STEER_PWMB_GPIO   GPIO_NUM_12

// ---- Potentiometer ADC -----------------------------------------------------
#define STEER_POT_ADC_UNIT    ADC_UNIT_1
#define STEER_POT_ADC_CHANNEL ADC_CHANNEL_6   // GPIO 34 = ADC1_CH6

// ---- LEDC (PWMB) -----------------------------------------------------------
// Channel 2 / Timer 1 — clear of drive motor (CH0, CH1 / TIM0)
#define STEER_LEDC_CHANNEL    LEDC_CHANNEL_2
#define STEER_LEDC_TIMER      LEDC_TIMER_1
#define STEER_PWM_FREQ_HZ     20000              // 20 kHz — inaudible, within TB6612FNG spec
#define STEER_PWM_RESOLUTION  LEDC_TIMER_10_BIT  // 0–1023

// ---- Potentiometer calibration (hardware-verified) -------------------------
// Pot is inverted: higher value = left, lower value = right.
#define POT_CENTER   2160
#define POT_LEFT     2475   // full-left hard stop
#define POT_RIGHT    1200   // full-right hard stop

// ---- P-controller tuning ---------------------------------------------------
#define STEER_MIN_DUTY   150   // minimum duty to overcome static friction
#define STEER_MAX_DUTY   1023   // ~88% of 1023 — fast slew, leaves headroom

// ---- Dead zones ------------------------------------------------------------
#define STEER_POT_TOLERANCE  80   // ADC counts — coast inside this band
#define STEER_AXIS_DEAD_ZONE 80   // thumbstick units — coast, don't drive to center

// ---- ADC averaging ---------------------------------------------------------
#define POT_BURST_SAMPLES   32
#define POT_HISTORY_SIZE     4

// ---- State -----------------------------------------------------------------
static adc_oneshot_unit_handle_t s_adc_handle      = NULL;
static int32_t                   last_logged_axis   = 0;
static int                       pot_history[POT_HISTORY_SIZE];
static int                       pot_history_idx    = 0;
static bool                      pot_history_filled = false;

// ---- Private helpers -------------------------------------------------------

static void steer_coast(void) {
    gpio_set_level(STEER_BIN1_GPIO, 0);
    gpio_set_level(STEER_BIN2_GPIO, 0);
    ledc_set_duty(LEDC_HIGH_SPEED_MODE, STEER_LEDC_CHANNEL, 0);
    ledc_update_duty(LEDC_HIGH_SPEED_MODE, STEER_LEDC_CHANNEL);
}

static int read_pot_raw(void) {
    int32_t sum = 0;
    for (int i = 0; i < POT_BURST_SAMPLES; i++) {
        int val = 0;
        adc_oneshot_read(s_adc_handle, STEER_POT_ADC_CHANNEL, &val);
        sum += val;
    }
    return (int)(sum / POT_BURST_SAMPLES);
}

static int32_t read_pot(void) {
    int raw = read_pot_raw();
    pot_history[pot_history_idx] = raw;
    pot_history_idx = (pot_history_idx + 1) % POT_HISTORY_SIZE;
    if (pot_history_idx == 0) pot_history_filled = true;

    int count = pot_history_filled ? POT_HISTORY_SIZE : pot_history_idx;
    if (count == 0) return (int32_t)raw;

    int32_t avg = 0;
    for (int i = 0; i < count; i++) avg += pot_history[i];
    return avg / count;
}

// ---- Public API ------------------------------------------------------------

void steering_init(void) {
    // BIN1, BIN2 as outputs (coast: both low)
    gpio_config_t io_conf = {
        .pin_bit_mask = (1ULL << STEER_BIN1_GPIO) | (1ULL << STEER_BIN2_GPIO),
        .mode         = GPIO_MODE_OUTPUT,
        .pull_up_en   = GPIO_PULLUP_DISABLE,
        .pull_down_en = GPIO_PULLDOWN_DISABLE,
        .intr_type    = GPIO_INTR_DISABLE,
    };
    gpio_config(&io_conf);
    gpio_set_level(STEER_BIN1_GPIO, 0);
    gpio_set_level(STEER_BIN2_GPIO, 0);

    // LEDC timer for PWMB
    ledc_timer_config_t timer_conf = {
        .speed_mode      = LEDC_HIGH_SPEED_MODE,
        .timer_num       = STEER_LEDC_TIMER,
        .duty_resolution = STEER_PWM_RESOLUTION,
        .freq_hz         = STEER_PWM_FREQ_HZ,
        .clk_cfg         = LEDC_AUTO_CLK,
    };
    ledc_timer_config(&timer_conf);

    // LEDC channel for PWMB
    ledc_channel_config_t ch_conf = {
        .gpio_num   = STEER_PWMB_GPIO,
        .speed_mode = LEDC_HIGH_SPEED_MODE,
        .channel    = STEER_LEDC_CHANNEL,
        .timer_sel  = STEER_LEDC_TIMER,
        .duty       = 0,
        .hpoint     = 0,
    };
    ledc_channel_config(&ch_conf);

    // ADC1 for potentiometer wiper
    adc_oneshot_unit_init_cfg_t adc_init = {
        .unit_id  = STEER_POT_ADC_UNIT,
        .ulp_mode = ADC_ULP_MODE_DISABLE,
    };
    adc_oneshot_new_unit(&adc_init, &s_adc_handle);

    adc_oneshot_chan_cfg_t chan_cfg = {
        .atten    = ADC_ATTEN_DB_12,   // 0–3.3 V full-scale
        .bitwidth = ADC_BITWIDTH_12,   // 0–4095
    };
    adc_oneshot_config_channel(s_adc_handle, STEER_POT_ADC_CHANNEL, &chan_cfg);

    // Prime the running average buffer
    for (int i = 0; i < POT_HISTORY_SIZE; i++) pot_history[i] = read_pot_raw();
    pot_history_filled = true;

    int pot_val = read_pot();
    ESP_LOGI(TAG, "Steering init: BIN1=GPIO%d BIN2=GPIO%d PWMB=GPIO%d POT=ADC1_CH%d val=%d",
             STEER_BIN1_GPIO, STEER_BIN2_GPIO, STEER_PWMB_GPIO, STEER_POT_ADC_CHANNEL, pot_val);
}
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

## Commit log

2026-04-04 Phase 1: BLE motor control with Bluepad32
    - Bluepad32 custom platform for Xbox Controller over BLE
    - TB6612FNG Channel A: drive motors (LT forward, RT reverse)
    - TB6612FNG Channel B: steering stepper (left thumbstick X)
    - LED headlight toggle (Y button)
    - Disconnect safety stop on all outputs
    [led.c, main.c, motor_control.c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]
2026-04-04 Add logging for motor speed and steering position changes
2026-04-04 Fix steering dead zone (80) and add motor/steering logging
    - Increase thumbstick dead zone from 50→80 (stick rests at ~48-52)
    - Add ESP_LOGI for motor speed/direction and steering position
    - Remove verbose raw gamepad debug output
    - Verified: LT=FWD, RT=REV, stick=steer, Y=LED all working
    [my_platform.c]
2026-04-04 Remap GPIOs to contiguous left-side devkit pins
    - All TB6612FNG + LED pins now on ESP32 left side (32,33,25,26,27,14,12,13)
    - Matches TB6612FNG right-side pin order for straight wiring
    - LED moved from GPIO 4 to GPIO 13 (GPIO 34 is input-only)
2026-04-05 Switch steering from H-Bridge to servo PWM
    - Steering is a servo, not a stepper motor
    - 50Hz PWM on GPIO 27: 1ms (left) → 1.5ms (center) → 2ms (right)
    - Freed up TB6612FNG Channel B (BIN1, BIN2, PWMB no longer used)
    - Updated FSD to reflect servo-based steering
    [steering.c]
2026-04-05 Revert STBY to GPIO 26 (matches physical H-Bridge wiring)
    [motor_control.c]
2026-04-05 Servo on GPIO 13, LED on GPIO 4
2026-04-05 Closed-loop steering: DC motor + potentiometer via TB6612FNG Channel B
    - Reads pot on GPIO 34 (ADC) for current wheel position
    - Drives steering motor via Channel B (BIN1=27, BIN2=14, PWMB=12)
    - Proportional control: larger error = faster correction
    - Configurable center/min/max pot values for calibration
    - LED moved to GPIO 4
    [steering.c]
2026-04-05 Fix steering: ADC averaging, direction correction, dead zone hold
    - 16-sample ADC averaging to reduce motor noise on pot reading
    - Fixed motor direction to match pot feedback polarity
    - Dead zone: stop motor entirely (no active centering)
    - Calibrated pot: center=2160, min=1800, max=2500
    - Max PWM=500 for smoother response
    [steering.c]
2026-04-05 Tune steering: expanded range, running average ADC, noise fix
    - POT_RIGHT expanded to 1200 for full left travel
    - 32-sample burst + 4-sample running average on ADC
    - Tolerance increased to 80 for stability
    - 100nF ceramic cap on GPIO 34 to GND filters motor EMI
    - Verified: steering works correctly with drive motor running
    [steering.c]
2026-04-05 Move LED to GPIO 13
2026-04-05 Update FSD pin mapping with verified GPIOs and KiCad module pin refs
    - Add ESP32-WROOM-32 module pin numbers (IO## format)
    - Add TB6612FNG physical pin numbers
    - Add 5-wire steering servo wiring table
    - Add additional components (cap, resistor, battery)
    - Fix VM voltage: 7.4V (was 5V)
    - Remove duplicate table header
    - Add KiCad schematic project (hardware/)
    [rc-xbox-controller.kicad_sch]
2026-04-05 Remove KiCad lock files and .history from tracking
2026-04-05 Add KiCad wiring schematic with all components
    [rc-xbox-controller.kicad_sch]
2026-04-05 Ignore KiCad backups and user prefs
2026-04-05 Add schematic exports (SVG + PDF)
2026-04-05 Updated schematic: ERC clean, re-exported SVG + PDF
    [rc-xbox-controller.kicad_sch]
2026-04-05 Safety: stop motors when both LT and RT pressed simultaneously
2026-04-06 Add OTA update functionality and Wi-Fi configuration
    - Introduced OTA update handler in `ota.c` and `ota.h` for managing firmware updates.
    - Implemented a simple HTTP server in `webserver.c` and `webserver.h` to handle firmware uploads via a web interface.
    - Added Wi-Fi connection management in `wifi.c` and `wifi.h`, allowing the device to connect to a specified network for OTA updates.
    - Created Kconfig options for Wi-Fi SSID and password in `Kconfig.projbuild`.
    - Defined partition layout in `partitions.csv` to support OTA updates.
    [partitions.csv]
2026-04-07 Refactor hardware schematics: update GPIO assignments and add power flag symbols
    [rc-xbox-controller.kicad_sch]
2026-05-15 Refactor motor control and steering components for BTS7960 H-Bridge compatibility; update documentation and GPIO configurations
